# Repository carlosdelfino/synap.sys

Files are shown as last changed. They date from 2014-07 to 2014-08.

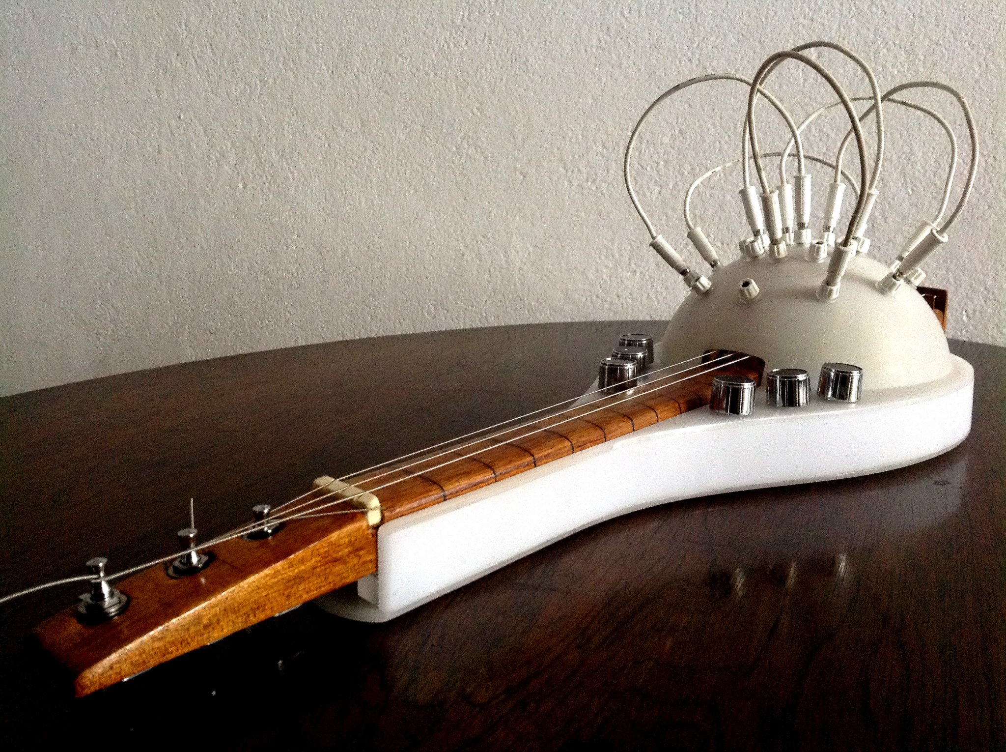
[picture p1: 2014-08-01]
imgs/synap.sys-pronto-henrique-roscoe.jpg

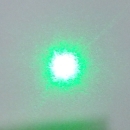
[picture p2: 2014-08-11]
docs/Medida de Brilho do Laser/laser 1.jpg

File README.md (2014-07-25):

#SYNAP.SYS

Um novo instrumento que Henrique Roscoe (www.1mpar.com) construindo para uma performance do HOL, chamado synap.sys.  É um instrumento que se parece com um synth modular analógico - os furos na parte esférica permitem uma ampla gama de possibilidades de conexão. Cada nova conexão entre os inputs muda som e imagem, de acordo com a parte que está sendo tocada. Tem uma parte analógica das cordas de guitarra que entra no computador como input de áudio, que é analisado via FFT e controla outros parâmetros da performance, além de ter o próprio som das cordas. 

Controlado com Arduino, consultoria em desenvolvimento Carlos Delfino.

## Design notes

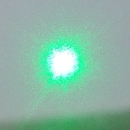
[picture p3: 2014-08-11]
docs/Medida de Brilho do Laser/laser 2.jpg

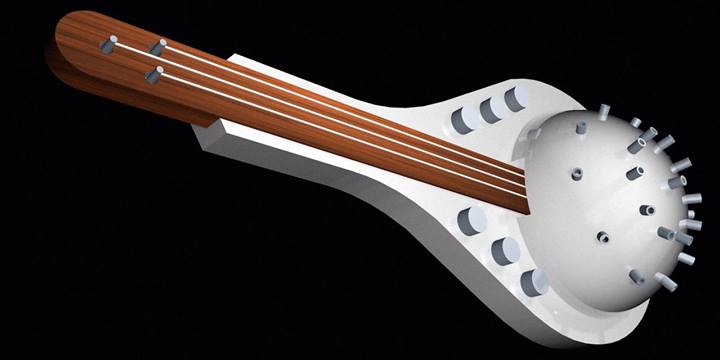
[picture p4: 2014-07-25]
imgs/synap.sys-henrique roscoe.jpg

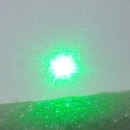
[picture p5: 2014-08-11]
docs/Medida de Brilho do Laser/laser 5.jpg

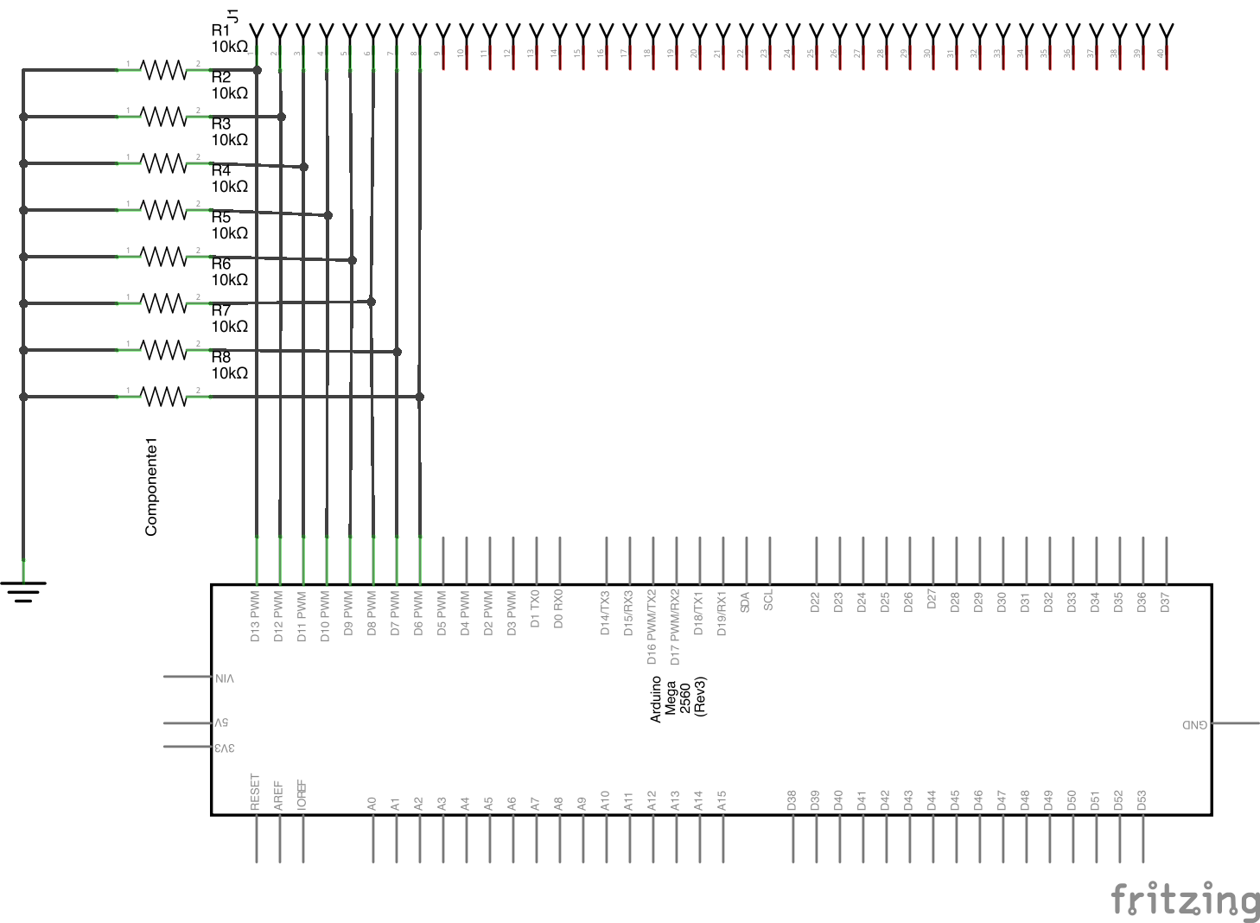
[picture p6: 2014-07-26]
esquemas/synap.sys/synap.sys_Esquemático.png

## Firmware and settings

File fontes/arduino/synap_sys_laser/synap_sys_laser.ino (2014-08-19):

#include <avr/interrupt.h>
#include <avr/io.h>
#include <Servo.h>
#include "debug.h"
#include "parameters.h"
#include "serialcmd.h"

long lastTimeTempHeatSink, lastTimeTempRoom, lastTimeTempInternal;

void setup() {
  Serial.begin(9600);

  setupSerialCmd();
  setupLasers() ;
  setupServos() ;

  lastTimeTempHeatSink = lastTimeTempRoom = lastTimeTempInternal = millis();
}

void loop() {
  long time = millis();
  if ((time - lastTimeTempHeatSink) > DELAY_TEMP_HEAT_SINK) {
    Serial.print("/temp/heatsink/");
    double temp = readHeatSinkTemp();
    Serial.print(temp);
    Serial.println("/");
    lastTimeTempHeatSink = time;
  }
  delayMicroseconds(DELAY_TEMP_INTER_READ);

  time = millis();
  if ((time - lastTimeTempRoom) > DELAY_TEMP_ROOM) {
    Serial.print("/temp/room/");

    double temp = readRoomTemp();
    Serial.print(temp);
    Serial.println("/");

    analogReference(DEFAULT);
    lastTimeTempRoom = time;
  }
  delayMicroseconds(DELAY_TEMP_INTER_READ);

// estou tendo problemas em fazer a leitura interna, porque uso com 1.1V
// e ao trocar a tensao de referencia toda as leituras em tensoes diferentes param
// mesmo dando o tempo certo para retornar a tensao certa.
  time = millis();
  if ((time - lastTimeTempInternal) > DELAY_TEMP_INTERNAL) {
    Serial.print("/temp/internal/");
    Serial.print(readInternalTemp());
    Serial.println("/");
    lastTimeTempInternal = time;
  }
  delayMicroseconds(DELAY_TEMP_INTER_READ);
  
}

double readRoomTemp() {
#if (TEMP_AREF == (DEFAULT))  // para leitura com 5V de referencia
  ADMUX =  _BV(REFS0) ; // 5V (VCC)
  const double fator = .48828125;
#elif (TEMP_AREF == (INTERNAL))  // para leitura com 1.1V de referencia
  ADMUX = _BV(REFS1) | _BV(REFS0); // 1.1V (VCC)
  const double fator  = .107421875;
#else
  ADMUX = _BV(REFS1) | _BV(REFS0); // 1.1V, mas esta aqui nao ' configurado
  const double fator = 0;
#endif
  ADCSRB = 0;
  ADCSRA |= _BV(ADEN);  // enable the ADC

  ADMUX |= _BV(MUX0); // porta A1
  ADCSRA |= _BV(ADEN);  // enable the ADC
  delay(20);

  // descarto a primeira leitura
  ADCSRA |= _BV(ADSC);
  while (bit_is_set(ADCSRA, ADSC));

  double temp = 0;
  byte mean = 0;
  for (; mean < MEAN_TEMP_INTERNAL; mean++) {
    ADCSRA |= _BV(ADSC);
    while (bit_is_set(ADCSRA, ADSC));
    byte l = ADCL;
    int h = ADCH;
    temp += (( h << 8) | l);
    delay(2);
  }
  temp /= mean;

  temp  *= fator;
  return temp;
}

/*
 * baseado no codigo: http://playground.arduino.cc/ComponentLib/Thermistor2
 */
double readHeatSinkTemp() {
  ADMUX =  _BV(REFS0); // nao precisa setar o MUX porque todos sao 0000, porta A0
  ADCSRA |= _BV(ADEN);  // enable the ADC
  delay(20);

  //descarto a primeira leitura
  ADCSRA |= _BV(ADSC);
  while (bit_is_set(ADCSRA, ADSC));

  double temp = 0;
  byte mean = 0;
  for (; mean < MEAN_TEMP_INTERNAL; mean++) {
    ADCSRA |= _BV(ADSC);
    while (bit_is_set(ADCSRA, ADSC));
    byte l = ADCL;
    int h = ADCH;
    temp += (( h << 8) | l);
    delay(2);
  }
  temp /= mean;
  
  temp = log(10000.0 * (1024.0 / temp - 1));
//  temp = log(10000.0 / (1024.0 / temp - 1)); // for pull-up configuration
  temp = 1 / (0.001129148 + (0.000234125 + (0.0000000876741 * temp * temp )) * temp );
  temp -= 273.15;            // Convert Kelvin to Celcius
 
  return temp;
}

//https://code.google.com/p/tinkerit/wiki/SecretThermometer
double readInternalTemp() {
  ADMUX = _BV(REFS1) | _BV(REFS0) |  _BV(MUX3);

  ADCSRA |= _BV(ADEN);  // enable the ADC

  delay(20);

  // descarto a primeira leitura;
  ADCSRA |= _BV(ADSC);
  while (bit_is_set(ADCSRA, ADSC));

  double temp = 0;
  byte mean = 0;
  for (; mean < MEAN_TEMP_INTERNAL; mean++) {
    ADCSRA |= _BV(ADSC);
    while (bit_is_set(ADCSRA, ADSC));
    int l = ADCL;
    int h = ADCH;
    temp += (( h << 8) | l);
    delay(2);
  }
  temp /= mean;

  temp = (temp - TEMP_INTERNAL_TOS) / TEMP_INTERNAL_K;
  return temp;
}

/********************
setup do laser
*/
void setupLasers() {

  Serial.println("\n/init/lasers/check");
  String str;

  Cmd cmds = (Cmd)malloc(sizeof(Cmd));

  for (byte b = 0; b < NUM_LASERS; b++) {

    cmds->id = b;

    pinMode(LASERS[cmds->id], OUTPUT);

    cmds->event = HIGH;
    laserCmdEvent(cmds);

    delay(DELAY_SETUP_INTER_LASERS);

    cmds->event = !cmds->event;
    laserCmdEvent(cmds);

    if (DEBUG_INIT) {
      str = "/DEBUG/LASER/";
      str += b;
      Serial.println(str);
    }
  }

  free(cmds);

  Serial.println("\n/init/lasers/ok");
}

/********************
setup do Servos
*/
void setupServos() {
  Serial.println("\n/init/servos/check");
  String str;

  Cmd cmds = (Cmd)malloc(sizeof(Cmd));

  for (byte b = 0; b < NUM_SERVOS; b++) {

    cmds->id = b;

    attachServo(cmds);

    cmds->event = MAX_SERVO_ANGLE;
    servoCmdEvent(cmds);
    delay(SERVO_DELAY_TEST);
    cmds->event = MIDLE_SERVO_ANGLE;
    servoCmdEvent(cmds);
    delay(SERVO_DELAY_TEST);
    cmds->event = MIN_SERVO_ANGLE;
    servoCmdEvent(cmds);
    delay(SERVO_DELAY_TEST);

    if (DEBUG_INIT) {
      str = "/DEBUG/SERVO/";
      str += cmds->id;
      str += "/";
      str += cmds->event;
      Serial.println(str);
    }
  }

  free(cmds);

  Serial.println("\n/init/servos/ok");
}

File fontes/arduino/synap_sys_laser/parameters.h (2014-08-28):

#ifndef PARAMETERS_H
#define PARAMETERS_H 1

#include "Arduino.h"
#include "limits.h"
#include "debug.h" 


#if DEBUG > 0
#define SYNAP_SYS_BOARD "Arduino DEBUG" 
const byte LASERS[]    = { 2,  3,  4,  5,  6};
const byte SERVOS[]    = {12, 11, 10,  9,  8};
#elif defined(__AVR_ATmega2560__)  || defined(__AVR_ATmega1280__)  // Arduino Mega e Variantes
//#elif defined(ARDUINO_ARCH_AVR) && defined(ARDUINO_AVR_MEGA2560)
#define SYNAP_SYS_BOARD "Arduino MEGA"
const byte LASERS[]    = { 2,  3,  4,  5,  6};
const byte SERVOS[]    = {12, 11, 10,  9,  8};
#elif defined(__AVR_ATmega328P__) // Arduino UNO
//#elif defined(ARDUINO_ARCH_AVR) && defined(ARDUINO_AVR_UNO)
#define  SYNAP_SYS_BOARD "Arduino UNO"
const byte LASERS[]    = { 2,  3,  4,  5,  6};
const byte SERVOS[]    = {12, 11, 10,  9,  8};
#else
#error "Este codigo ainda nao esta pronto para outras plataformas"
#endif



#define TEMP_INTERNAL_TOS  320.57
#define TEMP_INTERNAL_K    1.22

#define MEAN_TEMP_ROOM      10
#define MEAN_TEMP_INTERNAL  10
#define MEAN_TEMP_HEAT_SINK  10


#define PIN_TEMP_HEAT_SINK A0
#define PIN_TEMP_ROOM      A1


const byte NUM_LASERS  = sizeof(LASERS) / sizeof(*LASERS);
const byte NUM_SERVOS  = sizeof(SERVOS) / sizeof(*SERVOS);

#define MAX_SERVO_ANGLE 179
#define MIDLE_SERVO_ANGLE (MAX_SERVO_ANGLE/2)
#define MIN_SERVO_ANGLE 0
#define SERVO_DELAY_TEST 250

#define DELAY_TEMP_ROOM          (1000)
#define DELAY_TEMP_HEAT_SINK     (1000)
#define DELAY_TEMP_INTERNAL      (1000)      // delay em milesegundos
#define DELAY_TEMP_INTER_READ    (10 * 1000) // delay em microsegundos
#define DELAY_SETUP_INTER_LASERS (50)

#define DELAY_SERIAL_CMD   (1)
#define TIMEOUT_SERIAL_CMD (6)




// user apenas DEFAULT ou INTERNAL
#define TEMP_AREF  (DEFAULT) // cuidado ao fazer esta mudanca vc pode danificar o arduino
#endif

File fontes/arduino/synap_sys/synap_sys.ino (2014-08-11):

/**
 * Firmware para controle do Synap.sys
 * Este codigo informa os pares de conexao no sinap.sys, valor de leitura de 
 * 4 potenciometres, alem de permitir controlar 2 LEDs no Arduino UNO ou 4 LEDs
 * no Arduino Mega.
 *
 * Para obtencao da sintaxe das mensagens enviadas e para controle dos LEDs veja
 * o arquivo Readme.md neste diretorio.
 * 
 */
#include "parameters.h"
#include "peers.h"
#include "pots.h"
#include "serialcmd.h" 

String str;

long potsOldValues[NUM_POTS] ;

void setup() {
  if (USE_LED13_NO_TIME)
    pinMode(13, OUTPUT);

  Serial.begin(9660);

  Serial.println("\n\n\n\n\n/init/begin");
  #ifdef SYNAP_SYS_BOARD
  str = "\n/init/";
  str += SYNAP_SYS_BOARD;
  Serial.println(str);
  #endif
  
  if (DEBUG) {
    Serial.println("/DEBUG/ENABLED");
  }

  if (DEBUG_INIT) {
    str = "/DEBUG/NUM_PINS/";
    str += NUM_PINS;
    Serial.println(str);
    str = "/DEBUG/NUM_POTS/";
    str += NUM_POTS;
    Serial.println(str);
  }


  Serial.println("\n/init/pins/check");
  for (byte b = 0; b < NUM_PINS; b++) {

    pinMode(PINS[b], OUTPUT);
    digitalWrite(PINS[b], LOW);
    pinMode(PINS[b], INPUT);
    if (DEBUG_INIT) {
      str = "/DEBUG/PIN/";
      str += b;
      str += "/INPUT/";
      str += digitalRead(PINS[b]) ? "ON" : "OFF";
      Serial.println(str);
    }
  }
  Serial.println("\n/init/pins/ok");

  setupLeds();

  if (DEBUG_INIT) {
    Serial.println("/DEBUG/STARTED\n");
  }

  str = "\n/init/delays/";
  str += DELAY_INPUT;
  str += "/";
  str += DELAY_OUTPUT;
  str += "/";
  str += DELAY_LOOP;
  str += "/";
  str += DELAY_LOOP_PINS;
  str += "/";
  str += DELAY_LOOP_POTS;
  Serial.println(str);

  Serial.println("\n/init/reset/oldpeers");
  resetOldPeers();
  
  Serial.println("\n/init/reset/peers");
  resetPeers();
  
  Serial.println("\n/init/pots");
  for (byte p = 0; p < NUM_POTS; p++) {
    long v = analogRead(POTS[p]);
    if( POT_LAG_TYPE == POT_LAG_TYPE_100)
      v = map(v,0,1023,0,100); 
    String str = "/POT/";
    str += p;
    str += "/";
    str += v;
    Serial.println(str);
    potsOldValues[p] = v;
  }

  Serial.println("\n/init/end");

}


byte c;
byte lastPin = 0;
long lastShowTime, lastLoopPinsTime, lastLoopPotsTime;

void loop() {
  if (DEBUG) Serial.println("**********************");

  long showTime = millis();
  if ((showTime - lastShowTime) > (DELAY_SHOW_TIME)) {
    if (USE_LED13_NO_TIME) {
      digitalWrite(13, !digitalRead(13));
    } else {
      str = "/loop/time/";
      str += showTime;
      Serial.println(str);
    }
    lastShowTime = showTime;
  }

  long loopPinsTime = millis();
  if (DELAY_LOOP_PINS < (loopPinsTime - lastLoopPinsTime)) {
    loopPins();
    lastLoopPinsTime = loopPinsTime;
  }

  long loopPotsTime = millis();
  if (DELAY_LOOP_POTS < (loopPotsTime - lastLoopPotsTime)) {
    loopPots();
    lastLoopPotsTime = loopPotsTime;
  }

  delay(DELAY_LOOP);

}

byte lastPotRead = 0;
void loopPots() {
  byte p = lastPotRead++;
  if (lastPotRead >= NUM_POTS)
    lastPotRead = 0;

  long v = analogRead(POTS[p]);
  long old = potsOldValues[p];
  byte lag;
  if(POT_LAG_TYPE == POT_LAG_TYPE_100){
    v = map(v,0,1023,0,100);
  }
  byte a = abs(old - v);
  
  switch (POT_LAG_TYPE) {
    case POT_LAG_TYPE_SIN_1:
      if (a < 23)
        lag = POT_LAG_MIN;
      else if (a > 1000)
        lag = POT_LAG_MAX;
      else
        lag  = abs(POT_LAG * sin(map(a, 0, 1023, 0, 360)));
      break;
    case POT_LAG_TYPE_100:
      lag = 1;
      break;
    default:
      lag  = POT_LAG;
      break;
  }

  if (DEBUG_POTS) {
    String str = "/DEBUG/POTS/";
    str += p;
    str += "/old/";
    str += old;
    str += "/value/";
    str += v;
    str += "/abs/";
    str += a;
    str += "/lag base/";
    str += POT_LAG;
    str += "/lag calc/";
    str += lag;
    str += "/abs > lag/";
    str += a > lag ? "true" : "false";
    Serial.println(str);
  }

  if (a > lag) {
    String str = "/POT/";
    str += p;
    str += "/";
    str += v;
    Serial.println(str);
    potsOldValues[p] = v;
  }
}


void loopPins() {
  c = 0;

  for (byte p_out = 0; p_out < NUM_PINS && c < NUM_PEERS; p_out++) {
    bool nextOutput = false;

    // retorna o ultimo pino usado para o estado INP
    pinMode(PINS[lastPin], INPUT);
    lastPin = p_out;

    delay(DELAY_OUTPUT);

    pinMode(PINS[p_out], OUTPUT);
    digitalWrite(PINS[p_out], HIGH);


    if (DEBUG_OUTPUT) {
      str = "\n/DEBUG/PIN/OUTPUT/";
      str += p_out;
      Serial.println(str);
    } // DEBUG

    for (byte p_in = 0; p_in < NUM_PINS; p_in++) {
      if (p_in == p_out) continue;

      delay(DELAY_INPUT);
      bool pinState = digitalRead(PINS[p_in]);

      bool nextInput = false;

      if (DEBUG_INPUT) {
        str = "/DEBUG/PIN/";
        str += p_in;
        str += "/INPUT/";
        str += pinState ? "ON" : "OFF";
        Serial.println(str);
      } // DEBUG

      for (byte pair = 0; pair < NUM_PEERS  && c < NUM_PEERS; pair++) {
        if (DEBUG_PAIR2) {
          str = "/DEBUG/PAIR2/";
          str += pair;
          str += "/";
          str += pairPin1(pair);
          str += "/";
          str += pairPin2(pair);
          Serial.println(str);
        }// DEBUG

        if (usedPin(pair, p_in)) {
          nextInput = true;
          break;
        }
      }
      if (nextInput) continue;

      if (pinState) {
        if (DEBUG_PAIR1) {
          str = "\n/DEBUG/PAIR1/PIN/ON/";
          str += p_out;
          str += "/WITH/";
          str += p_in;
          str += "\n";
          Serial.println(str);
        } // DEBUG

        setPair(c++, p_in, p_out);

        nextOutput = true; // vou para a proxima entrada, apenas um par por output;
        break;
      }
    } //FINDA FOR INPUT

    digitalWrite(PINS[p_out], LOW);
    if (nextOutput) continue;
  } // FINALIZA FOR OUTPUT

  showPeers();
  movePeers();
}

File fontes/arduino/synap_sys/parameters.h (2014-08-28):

#ifndef PARAMETERS_H
#define PARAMETERS_H 1

#include "Arduino.h"
#include "debug.h"
#include "pots_lag_types.h"

//#ifdef ARDUINO_ARCH_AVR
//#error "Este codigo foi criado para a plataforma AVR de MCU"
//#endif


// identificacao dos pinos usados,
// o mapeamento nao e direto o pino 1 nao e necessariamente o mesmo pino no arduino
#if DEBUG > 0
#define SYNAP_SYS_BOARD "Arduino DEBUG" 
const byte PINS[]    = {2, 3, 4, 5, 6, 7};
const byte POTS[]    = {A2, A3};
const byte LEDS[]    = {A5};
#elif defined(__AVR_ATmega2560__)  || defined(__AVR_ATmega1280__)  // Arduino Mega e Variantes
//#elif defined(ARDUINO_ARCH_AVR) && defined(ARDUINO_AVR_MEGA2560)
#define SYNAP_SYS_BOARD "Arduino MEGA"
const byte PINS[]    = {24, 30, 4, 5, 7, 22, 28, 23, 29, 33, 27, 35, 2, 3, 6, 37, 26, 32, 31, 25, 34};
const byte POTS[]    = {A1, A2, A3, A4};
const byte LEDS[]    = {36, 38, 39, 40};
#elif defined(__AVR_ATmega328P__) // Arduino UNO
//#elif defined(ARDUINO_ARCH_AVR) && defined(ARDUINO_AVR_UNO)
#define  SYNAP_SYS_BOARD "Arduino UNO"
const byte PINS[]    = {2, 3, 4, 5, 6, 7, 8, 9, 10, 11, 12};
const byte POTS[]    = {A1, A2, A3, A4};
const byte LEDS[]    = {A0, A5};
#else
#error "Este codigo ainda nao esta pronto para outras plataformas"
#endif

// define o lag entre valores para informar um alteracao no valor da leitura analogica
#define POT_LAG (15)
#define POT_LAG_MIN 3
#define POT_LAG_MAX 3

#define MSG_PIN_ON  "1"
#define MSG_PIN_OFF "0"

// indica que deve ser usado LED13 no lugar do time
#if DEBUG > 0
#define USE_LED13_NO_TIME false
#else
#define USE_LED13_NO_TIME true
#endif

#ifndef USE_LED13_NO_TIME
#define USE_LED13_NO_TIME false
#endif

#define DELAY_OUTPUT (DEBUG?10:0)
#define DELAY_INPUT (DEBUG?10:0)
#define DELAY_LOOP (DEBUG?10:3)
#define DELAY_LOOP_PINS (DEBUG?30:30)
#define DELAY_LOOP_POTS (DEBUG?30:10)
#define DELAY_SERIALCMD_READ (DEBUG?2:10)

#if USE_LED13_NO_TIME
#define DELAY_SHOW_TIME (DEBUG?300:500)
#else
#define DELAY_SHOW_TIME (DEBUG?300:3000)
#endif

#endif

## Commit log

2014-07-26 esquema para referencia e fontes em estágio de depuração
    [synap.sys.fzz]
2014-07-26 primeira versão para testes nesta versão inda há erros a serem corrigidos já identificados Há dois arquivos o synap_sys.ino que o padrão do arduino e contem a logica principal, o arquivo parameters.h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
    [parameters.h, synap_sys.ino]
2014-07-26 primeiro release para testes
2014-07-26 mudança do termo par por pair e pares por peers O array pares, foi mudado para _peers usando traço baixo no nome da variavel para caracterizar que está oculta;
2014-07-26 Corrigido o bug que não exibia os pares apos o primeiro loop outras correções menores
    [parameters.h, synap_sys.ino]
2014-07-27 Implementado eventos ON e OFF para pares Seccionado arquivos separando funções relativas ao PEER neste release passa a funcionar o evento OFF. o evento ON somente é enviado quando ocorre a primeira v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
2014-07-27 encapsulado o algoritimo de tratamento dos pinos em uma função também inserido controle de tempo de execução sem atraso evitando o uso de Delay();
2014-07-27 Adicionados parametros iniciais para uso com POTs adotado o uso do led13 para sinalização de processamento
2014-07-27 Adicionado algorimo de leitura dos potencimetros
2014-07-27 Corrigido o limite de potencimetros a ler. adcionado mais detalhes de depuração
    [parameters.h, synap_sys.ino]
2014-07-27 Implementnado Novo algoritmo curva de amostragem e ajuste de curva
    O potenciometro pode ser lido ponto a ponto, ou pode ter sua amostragem
    espaçada para evitar leituras excessivas, havendo um lag fixo de x pontos
    a cada leitura ou este lag pode variar quando mais proximos dos extremos
    aumentando o número de amostragens.
    O valor lido também pode ser ajustado, por exemplo um limite de 0 a 100
    ou seja 0 a 100%, ou mesmo um potenciometro logaritimo pode se tornar
    linear e o linear logaritimo.
    O unico algoritmo implementado é o de limite de valores
    [parameters.h, synap_sys.ino]
2014-07-28 Corrigido parametros de compilação para reconhecimento de plataforma Por motivo desconhecido não está reconhecendo o MOdelo MEGA Também restruturado o diretório dos esquemas
    [synap.sys.fzz]
2014-07-29 Corrigido a identificação do Arduino UNO e também do MEGA
    [parameters.h]
2014-07-29 Adicionado identificação da placa usada Indentificação basica apenas para ajudar na depuração ajuste na mensagem de debug "ENABLED" para quando ativa
2014-07-30 implmentado o uso de comando para ligar e desligar leds. primeira versão, atende as necessidades, porém não é a ideal ainda. separado as informações de debug do arquivo parameters
2014-07-31 Erro no arquivo parameters.h corrigido
    [parameters.h]
2014-08-01 Ajustes menores no parametros de debug.
2014-08-09 codigo usado para testar o shield laser/servo
2014-08-10 Terminado a primeira versão controlador do Laser.
2014-08-11 Analise dos Lasers
2014-08-11 quando em modo debug a leitura da serial é mais lenta, porem sem o debug a leitura é muito rapida, causando perda de caracteres e fazendo com que o codigo acredite que ainda não se receber o comando.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
    Estarei pesquisando o uso de leitura com timeout para os comandos
    evitando este problema.
    [serialcmd.cpp, synap_sys.ino]
2014-08-11 Para metrizei o delay para vlaores difernetes durante o debug.
2014-08-11 Devolvido o codigo de leitura do potenciometor e pares.
2014-08-12 mudado a string que informa o valor do potenciometro. quando o valor do pontenciometor é enviado agora segue o seguinte formato /pot/1=20 ou seja evento pot (potenciometro) potenciometro 1 igual a 20%
2014-08-12 voltei a usar barra entre o codigo do potenciometro e valor carregado
2014-08-12 Releae com melhorias no circuito de alimentação melhorando as opções de regulagem, inserido também sensores de temperatura para alertar sobre aquecimento. Sugestões para versòes futuras são controle 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
    [laser control synap.sys.fzz]
2014-08-12 novo layout da placa com os novos reguladores de corrente ainda sendo desenhada os demais arquivos são apenas testes e serão levados para o master
    [laser control synap.sys.fzz]
2014-08-12 parametrizado a msg que informa se um par está ativo ou não anteriormente um partivo era sinalizado com on/off agora apenas 1/0
2014-08-14 Adicionei dois sensores de temperatura Um para o dissipador de calor e outro para a leitura do ambiente. Os sensores não foram ainda colocados no circuito e são montados externamente, e até é melhor 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
    Tentei usar o sensor interno de temperatura do ATMega328, porém ao fazer
    a mudança de tensão para 1.1V ocorre problemas em ambas as leituras.
    Sugestões são bem vindas.
    [parameters.h, synap_sys_laser.ino]
2014-08-14 Novo layout para a placa com regulador de corrente por laser. Neste novo circuito limito a corrente de cada laser. A intensão é em projetos futuros poder controlar dois níveis de corrente máximo para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
    [laser control synap.sys.fzz]
2014-08-14 Liberado o código e parametrizado a leitura da temperatura interna. Corrigido erros no circuito que ocasiovam falhas na leitura
    [parameters.h, synap_sys_laser.ino]
2014-08-19 aumentei o tempo e defini um parametro para controle deste tempo entre os testes do laser
2014-08-19 melhorias no algoritimo de comandos acredito que ainda pode melhor na velocidade e elegancia do código
2014-08-19 devolvido a leitura de temperatura.
2014-08-20 Update parameters.h
    reduzi o tempo de espera do caracter
